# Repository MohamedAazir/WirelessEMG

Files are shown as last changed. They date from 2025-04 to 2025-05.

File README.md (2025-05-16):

# Wireless sEMG Monitoring Device

<div align="center">
  Breadboard Implementation
</div>

This is the repository of a wireless EMG device built for our module **BM2210-Bio Medical Device Design**. The device senses the forearm muscle signals on flexion and extension and then goes through an amplification and filtering part which at last will be transmitted to a laptop where the classification happens. The speciality of the device is that most of the main circuitry of the device was developed using analog electronic components.

## Repository Contents

- 🔌 **Circuit Design**
- 🧪 **Simulation Results**  
- 🔧 **Breadboard Implementation** 
- 🧩 **PCB Design**  
- 🧱 **Enclosure Design**   
- 📡 **Wireless Transmission**  
- 🤖 **ML Model Development**  
- 📄 **Documentation**

## 🔌 Circuit Design

The circuit design consists of four main parts: an **instrumentation amplifier**, a h**igh-pass filter**, a **low-pass filter**, and a **notch filter**. Each part plays a critical role in conditioning the raw bioelectrical signals before further processing or analysis.

### 1. 🎛️ Instrumentation Amplifier

This stage is responsible for amplifying the weak differential signal received from the electrodes while rejecting common-mode noise. It ensures that even very small biopotential signals are amplified to a usable level without being distorted by environmental interference. This is crucial in biomedical applications where the signal strength is often in the microvolt range and needs clean amplification before filtering.
<div align="center">
  Instrumentation Amplifier
</div>

### 2. 🔼 1st Order Active High Pass Filter

We use a **first-order active high-pass filter** with a cut-off frequency of **15.4 Hz**. The main purpose of this filter is to remove low-frequency components from the signal, including **DC offsets and motion artifacts** that can otherwise distort the meaningful parts of the bioelectrical signal. By using an active filter design, we ensure better performance and minimal signal attenuation in the passband.

<div align="center">
  HPF
</div>

### 3. 🔽 5th Order Bessel Low Pass Filter

To preserve the integrity of the signal's shape while eliminating high-frequency noise, we implement a **fifth-order Bessel low-pass filter**. This is achieved using a cascaded system comprising one 1st order active low-pass filter and two 2nd order active low-pass filters. The overall cut-off frequency is around **450 Hz to 460 Hz**. The Bessel filter is chosen for its linear phase response, which helps maintain the waveform fidelity of the signal—an important factor for downstream analysis and visualization.

<div align="center">
  LPF
</div>

### 4. 🚫 Twin-T Notch Filter

To eliminate **powerline interference at 50 Hz**, we use a twin-T notch filter. This type of filter is highly effective at attenuating a narrow frequency band, in this case, the frequency commonly introduced by electrical noise in power systems. Our implementation includes five potentiometers to fine-tune the filter: three are used to precisely set the notch frequency, and two are used to adjust the desired roll-off. This allows for flexibility in tuning and ensures that the filter performs effectively in different environments.

<div align="center">
  Notch Filter
</div>

## Simulation Results

We simulated our designed circuit using LT spice software where we able to visualize the frequency response of each filtering stage.  

<div align="center">
  HP Filter
</div>

The frequency response after the High pass filter

<div align="center">
  HP Filter
</div>

The frequency response after the Low pass filter

<div align="center">
  HP Filter
</div>

The frequency response after the Notch filter

## Breadboard Implementation

The breadboard implementation was used in the early stages for prototyping and testing the EMG signal acquisition, filtering, and wireless transmission before finalizing the PCB. It serves as a reference for understanding the initial circuit layout and testing procedure.

<div align="center">
  breadboard
</div>

## PCB Design

When designing the printed circuit board (PCB) for our wireless sEMG monitoring device, we utilized EasyEDA
software to design a **4-layer PCB**. This tool allowed us to efficiently create and simulate the PCB layout, ensuring optimal design for
signal conditioning, sampling, and wireless transmission. EasyEDA’s user-friendly interface and extensive
library of components made it well-suited for the development of this biomedical application. By leveraging
its advanced features, we were able to streamline the PCB design process and ensure the circuit met the
requirements of the wireless sEMG monitoring system.

<div align="center">
  PCB Layout
</div>

After finalizing the PCB, we choosed JLC PCB which is a professional PCB Manufacturer for the production of our PCBs.

<div align="center">
  PCB 3D Layout
</div>

## Enclosure Design

We used SOLIDWORKS software for the designing of the enclosure. The enclosure consists of a top lid, bottom part, and a battery compartment. The device is designed as a compact wearable design which makes it easy to fetch the EMG signals.
<div align="center">
  Enclosure1
</div>

<div align="center">
  Enclosure2
</div>

<div align="center">
  Enclosure3
</div>

## Coding & Wireless Transmission

The final filtered signal is transmissed using Wifi through an ESP32 micro controller to the host computer. The computer then samples the signal and sends it through a digital filtering process using the **scipy** library. Then the final values are saved as a .csv file to be classified in the ML model.

## ML Model Development

A detailed description of the ML model is shown [here](MLmodel/)

## Our Team 

- Praveen Samuditha
- Hansani Kaumadhi
- Mohamed Aazir

<div align="center">
  Enclosure3
</div>

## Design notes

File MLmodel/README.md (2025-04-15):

# 🤖 Wrist Flexion Detection - ML Model

This is a part of our **Biomedical Device Design** project. It includes a machine learning pipeline to classify wrist flexion based on biosignal input.

---

## 🧩 Overview

This includes:

- Training a **Random Forest Classifier** using handcrafted features
- signal classification display via **Streamlit** app
- A lightweight CLI tool for batch or test use

---

## 📁 Files in This Folder

| File | Description |
|---|---|
| `random_forest_updated.py` | Trains the model and saves it as `.joblib` |
| `app_updated.py` | Streamlit-based app for uploading and classifying signals|
| `real_time_clf.py` | CLI tool for running classification from CSV input |
| `random_forest_updated_model.joblib` | Trained model file (generated after training) |

---

## 📊 Features Used for Classification

From each `Amplitude` signal, we extract **7 statistical features**:

- Mean
- Standard Deviation
- Maximum
- Minimum
- Range
- Median
- Root Mean Square (RMS)

<p align="center">
  
</p>

These features are passed to the Random Forest model for classification.

## 📊 Model Evaluation

<p align="center">
  
</p>

---

## 🖼️ App Preview

<p align="center">
  
  
</p>

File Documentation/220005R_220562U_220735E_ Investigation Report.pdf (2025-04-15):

# Investigation Report

### Team MediCore Innovations


# BM2210 - Bio Medical Device Design

## Group Members

Name | Index Number
Aazir M. A. M. Samuditha H. K. P. Yashodhara M. H. K. | 220005R 220562U 220735E

## Contents

1 Introduction | 3
2 Our Strategic Focus | 3
3 Need 1: Arterial Blood Speed Measuring Device | 4
4 Need 2: Automated Laparoscopic Intracorporeal Knotting Device | 6
5 Need 3: Low-Cost Wireless sEMG Signal Detection System for Wrists | 8
6 Needs Screening | 10
7 Conclusion | 11
8 References | 12

## 1 Introduction

Medicore Innovations is a startup focused on about biomedical product design and development. We’re a bunch of second-year students studying biomedical electronic engineering. Our goal is to shake things up in healthcare and come up with cool, new ways to make medical tech better and easier to get for everyone.

## 2 Our Strategic Focus

### 2.1 Mission

Our mission is to transform healthcare by designing cutting-edge biomedical devices that are not only innovative but also highly affordable, with a strong focus on serving the Sri Lankan market.

### 2.2 Our Focus

Despite our current limits in sophisticated anatomy and complex electronics, Medicore Innovations focuses on creativity and resourcefulness, leveraging the skills of its driven team of undergraduates. Through leveraging a solid basis in fundamental electronics and an unwavering dedication to education, the firm hopes to enhance healthcare accessibility and cost. They focus on developing affordable biomedical devices that satisfy the needs of healthcare providers, NGOs, government agencies, and people looking for affordable medical solutions, while overcoming obstacles like time constraints and a lack of local resources. They primarily target the South Asian market, with Sri Lanka as their primary market.

## 3 Need 1: Arterial Blood Speed Measuring Device

### 3.1 Introduction and Background

Accurately measuring arterial blood flow is super important in healthcare, especially during emergencies like accidents. It helps us figure out if blood vessels are working right or if there’s a blockage that needs quick attention. Right now, we use blood speed measuring tools that rely on Doppler ultrasound tech. This tech sends out an ultrasound wave and checks how it bounces back from moving blood cells to see how fast the blood is flowing. But here’s the catch: in Sri Lanka, these devices can cost around 2 lakhs or even more. That makes it hard for many folks to get their hands on them. We need a more affordable option designed for the local market. Better access means better diagnostics without breaking the bank.

### 3.2 Source in the medical field

Resource Person: A vascular surgeon from Teaching Hospital Peradeniya
We consulted a vascular surgeon from Teaching Hospital Peradeniya regarding the need for an affordable arterial blood speed measuring device. Their expertise highlighted the high cost and limited accessibility of current devices in Sri Lanka, which hampers timely diagnosis and treatment of vascular issues, especially in emergency situations.

### 3.3 Need Statement

Problem: Medical professionals often face challenges in assessing arterial blood flow in emergency situations, such as accidents, due to the high cost and limited accessibility of current Doppler-based blood speed measuring devices. This can delay critical diagnostics and treatment, particularly in resource-limited settings like Sri Lanka.
Population: Doctors and emergency medical professionals, as well as patients requiring immediate evaluation of blood flow, especially in trauma cases.
Outcome: Develop an affordable arterial blood speed measuring device using Doppler ultrasound technology, specifically designed for the Sri Lankan market, to improve accessibility, enhance diagnostic accuracy, and expedite emergency care.

### 3.4 Existing Solutions

Current methods to measure how fast blood moves in arteries use Doppler ultrasound technology. This tech is popular in hospitals for checking health. Companies like D-Brown, Siemens, and GE Healthcare make devices that are super accurate. They give quick info on blood flow speed, which is important for finding blockages or other blood vessel problems. These machines have fancy sensors that can measure without hurting the patient and do it well, but the problem is they can cost a lot, often more than 2 lakhs. That makes it hard to get to places like Sri Lanka. Because of the high price and the need for special training to run these machines, many healthcare providers can’t adopt them easily in areas with limited resources.

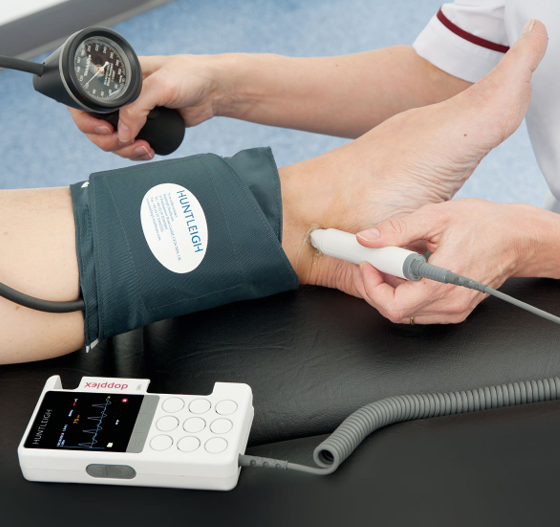
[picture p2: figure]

Figure 1: Existing Device for Arterial Blood Speed Measuring

### 3.5 Stakeholder and Market Analysis

Hospitals and Clinics: Healthcare providers, especially in areas with few resources, can really boost their diagnostic skills with an affordable device that measures arterial blood speed. Faster diagnostics can mean quicker treatments. That’s great for patient outcomes! Plus, hospitals won’t spend as much on importing pricey equipment. They can also offer better services to more people.
Doctors and Emergency Medical Professionals: Doctors will get a handy, budgetfriendly tool for checking blood flow in urgent situations. This helps them spot vascular problems quicker. Emergency professionals can make decisions fast, especially in trauma cases where keeping an eye on blood flow is super important.
Medical Device Manufacturers: Developing a low-cost Doppler-based blood speed measuring device opens a big chance in the market, especially in places like Sri Lanka. As more folks need easy-to-use diagnostic tools, manufacturers can reach out to underserved areas where low prices matter. Sure, the first costs of making them might be tough, but there’s a great chance for lots of use because everyone wants affordable healthcare.

The market for monitoring blood flow devices is growing consistently. There’s more cardiovascular disease and trauma happening around the world. Yet, the big challenge is still how affordable these devices are, particularly in developing countries. If we can provide a cost-effective solution, it might unlock new markets and help fulfill the rising wish for accessible medical diagnostics.

## 4 Need 2: Automated Laparoscopic Intracorporeal Knotting Device

### 4.1 Introduction and Background

Laparoscopic surgery is a common practice in the medical field because of its benefits of reduced recovery time, minimal scarring and lower risk of infection. However, intracorporeal knot tying, a key step in procedures such as suturing during laparoscopy, is one of the most technically challenging tasks for surgeons. The complexity of manually tying knots in a limited space can increase the risk of errors, increase the time of the surgery and lead to complications. The use of an automated device to perform laparoscopic knotting can reduce the technical burden on surgeons and reduce operation time.

### 4.2 Source in the medical field

Resource Person: A vascular surgeon from Teaching Hospital Peradeniya Additionally, the surgeon emphasized the challenges faced during laparoscopic surgeries, specifically with intracorporeal knotting. The complexity of manually tying knots in small spaces increases the risk of surgical errors and extends operation times, highlighting the need for an automated knotting device to improve efficiency and reduce risks.

### 4.3 Need Statement

Problem:Surgeons face difficulties when doing intracorporeal knotting during laparoscopic surgeries due to the complexity of manually tying knots in small spaces which can increase the risk of surgical errors and extend operation times.
Population: Surgeons performing laparoscopic procedures and patients who are going through these surgeries.
Outcome: Create a device that automates intracorporeal knotting to improve surgical efficiency, reduce errors and decrease the time required for laparoscopic operations.

### 4.4 Existing Solutions

Current solutions to intracorporeal knot tying in laparoscopic surgery include manual knot tying techniques and the use of pre-tied knot devices. But these methods come with limitations:
Manual Knot Tying: requires a lot of training and precision. Surgeons must be highly skilled to tie knots in limited spaces, which can lead to fatigue, errors and extended surgery time.
Pre-Tied Knot Devices: Eventhough pre-tied knots reduce the technical challenge, they lack flexibility in terms of custom knot placement and tightness.

Automated devices that perform suturing exist, but they are either too complex or costly, with limited availability in many regions including Sri Lanka. There is still a significant gap in the development of a user-friendly device for automating intracorporeal knotting.

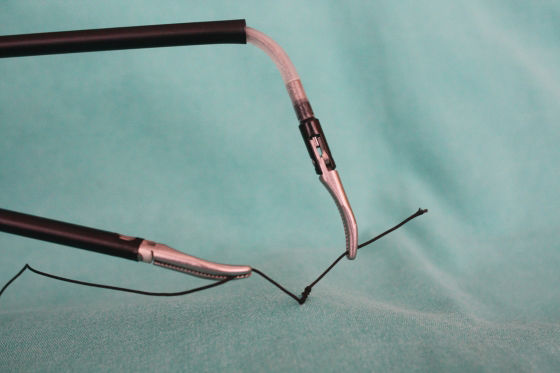
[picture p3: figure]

Figure 2: Existing Surgical Equipments for Intracorporeal Knotting

### 4.5 Stakeholder and Market Analysis

Patients: Patients who are going through laparoscopic surgery can benefit from shorter operation times, fewer complications and faster recovery as automated knotting can reduce surgical errors.
Surgeons:Surgeons will have an easier and more efficient method for knot tying, reducing stress and the probability of errors. Automation can free surgeons from repetitive time-consuming tasks and improve overall precision.
Hospitals and Surgical Centers: Healthcare providers can improve operating room efficiency and reduce costs associated with longer surgical procedures. Shorter surgery times also increase the number of surgeries that can be performed in a day improving income of the hospital.
Medical Device Manufacturers: The development of an automated intracorporeal knotting device presents a significant market opportunity. As laparoscopic surgery continues to expand globally, there is increasing demand for tools that improve surgical efficiency and outcomes.

The global market for laparoscopic devices is drastically increasing with the rising demand for minimally invasive surgeries. As the market expands, there is an increasing need for automation in surgical tasks that are time-consuming or technically challenging. An automated intracorporeal knotting device can meet this demand by improving surgeon performance and patient outcomes. Challenge may be the initial cost of developing and marketing the device, but the potential for widespread usage is high due to the benefits in terms of efficiency and safety. The market for such devices is expected to increase, especially in developed countries where laparoscopic surgeries are widely used.

## 5 Need 3: Low-Cost Wireless sEMG Signal Detection System for Wrists

### 5.1 Introduction and Background

Surface electromyography (sEMG) is a widely used technique to assess muscle activity and performance. Monitoring muscle health and performance is crucial for athletes, especially to track muscle fatigue, recovery, and potential abnormalities. Wrist muscles are particularly prone to fatigue due to repetitive movements in sports such as tennis, golf, and weightlifting. Traditional sEMG systems can be bulky, wired, and impractical for daily use. A wireless sEMG signal detection system for the wrist would provide real-time muscle monitoring in a convenient and wearable format, offering athletes a better idea of their muscle condition and performance while reducing the risk of injury.

### 5.2 Source in the medical field

Resource Person: A 2nd year MBBS undergraduate from University of Colombo
He provided us with the discussed problem and the need for a low cost wireless sEMG system for people specially in the field of sports.

### 5.3 Need Statement

Problem: Athletes often face challenges in monitoring their wrist muscles’ health and performance due to limitations in existing wired sEMG devices, which are bulky and unsuitable for daily, real-time tracking of muscle fatigue and abnormalities.
Population: Athletes and sportspersons who require daily monitoring of their wrist muscles to assess fatigue, prevent injury, and ensure optimal performance at a reasonable cost.
Outcome: Develop a wireless sEMG detection system for wrists that allows real-time monitoring of muscle fatigue and abnormalities. This system should improve athletic performance, prevent injuries, and enable daily, non-invasive monitoring.

### 5.4 Existing Solutions

Current sEMG systems include wired devices and sensors placed on the skin to detect muscle activity. While effective for clinical settings, they pose several limitations in sports and daily use:
Wired sEMG Devices: Though accurate, these systems limit movement, making them unsuitable for dynamic sports. The wires and bulky setup create discomfort, which can distract athletes from their activities.
Wearable Fitness Trackers: Some devices monitor general muscle performance, but they lack the precision of sEMG for detecting muscle fatigue and specific abnormalities. Wireless sEMG Devices: Existing wireless options are often expensive, and their bulkiness reduces comfort, particularly for sportspersons who need lightweight, flexible, and user-friendly designs.

There is a significant opportunity for a lightweight, wireless sEMG system that is cost-effective and designed specifically for daily monitoring of wrist muscles.

### 5.5 Stakeholder and Market Analysis

Athletes and Sportspersons: Athletes can benefit from precise, real-time data on wrist muscle performance, helping prevent overuse injuries, fatigue, and abnormal strain. Daily monitoring ensures better recovery and peak performance during training and competition.
Sports Medicine and Rehabilitation Professionals: A wireless sEMG system enables sports doctors and physiotherapists to monitor and track muscle health remotely, adjusting training or recovery programs based on real-time data.
Fitness Trainers: Coaches and trainers can use this device to improve training schedules by understanding an athlete’s muscle fatigue and recovery needs more accurately. Medical Device Manufacturers: There is a strong market for wearable, non-invasive, real-time monitoring devices in the sports and healthcare industries. The growing interest in personalized health data tracking provides a good opportunity for manufacturers.

The market for wireless sEMG devices is expanding as athletes and healthcare professionals seek more sophisticated tools for performance monitoring and injury prevention. This device can be a cost-effective solution for continuous wrist muscle monitoring, appealing to both professionals and everyday athletes. Though initial development and production costs may pose a challenge, the potential for widespread usage in sports medicine and fitness is significant, particularly in regions where injury prevention and performance tracking are a priority.

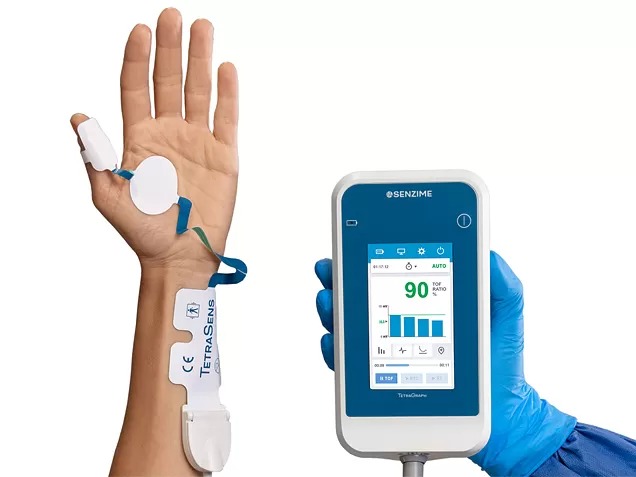
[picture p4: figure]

Figure 3: Wrist Muscle Activity Monitoring - An Improved Method

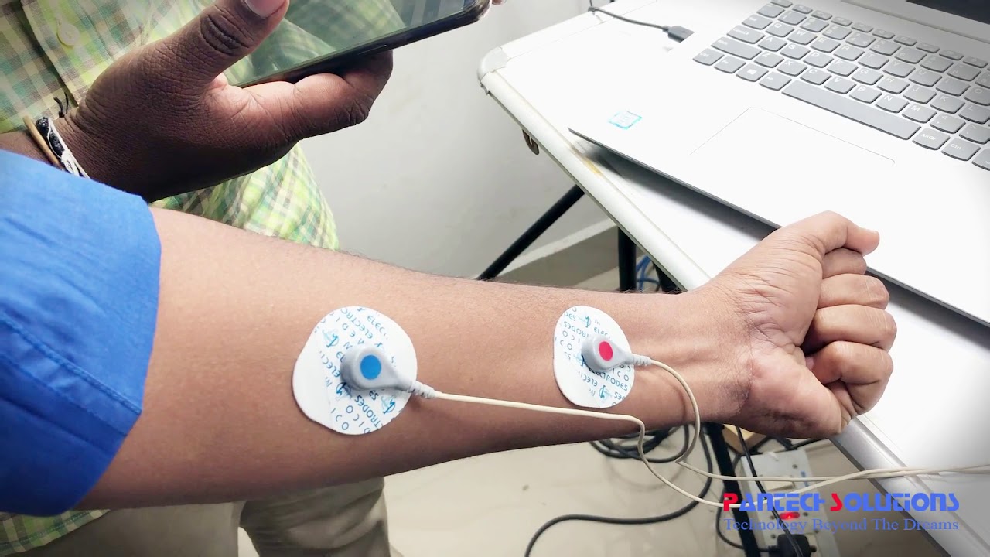
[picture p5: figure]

Figure 4: Wrist Muscle Activity Monitoring - A Conventional Method

## 6 Needs Screening

We considered the above problems and carried out a screening process by allocating marks. Then we selected the most suitable problem by the rankings.

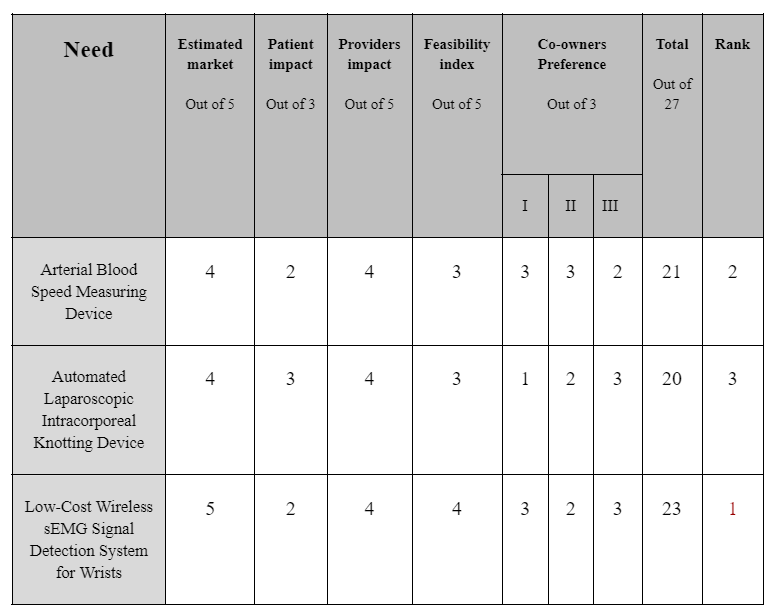
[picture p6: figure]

## 7 Conclusion

In conclusion, we identified ”Need 3: Low-Cost Wireless sEMG Signal Detection System for Wrists” as it meets a vital demand for real-time, non-invasive muscle activity monitoring. This tool can provide insightful information about how muscles work, which is helpful for clinical diagnoses, sports performance, and rehabilitation. In comparison to the other demands, it is a highly influential initiative because of its potential to improve patient care and provide more effective muscle testing in a variety of contexts.

## 8 References

- S. R. Jernigan, G. Chanoit, A. Veeramani, S. B. Owen, M. Hilliard, D. Cormier,
B. Laffitte, G. Buckner, ”A laparoscopic knot-tying device for minimally invasive cardiac surgery,” European Journal of Cardio-Thoracic Surgery, vol. 37, no. 3, pp. 626–630, Mar. 2010, doi: 10.1016/j.ejcts.2009.09.024. (https://doi.org/10.1016/j.ejcts.2009.09.024)
- T. G¨opel, F. H¨artl, A. Schneider, et al., ”Automation of a suturing device for minimally invasive surgery,” Surg Endosc, vol. 25, pp. 2100–2104, 2011, doi: 10.1007/s00464-010-1532-x. (https://doi.org/10.1007/s00464-010-1532-x)
- 18.102MUL, ”Laparoscopic Intracorporeal Suturing: Fundamentals and Tips & Tricks for New Learners,” YouTube, Aug. 7, 2015. [Online]. Available: https: //www.youtube.com/watch?v=U36O18Whc9c. [Accessed: Sep. 16, 2024].
- A. Yousefian, S. Roy, B. Gosselin, ”A Low-power wireless multi-channel surface EMG sensor with simplified ADPCM data compression,” 2013 IEEE International Symposium on Circuits and Systems (ISCAS), Beijing, China, 2013, pp. 2287-2290, doi: 10.1109/ISCAS.2013.6572334. (https://doi.org/10.1109/ISCAS.2013.6572334)
- Z. Liang, X. Wang, J. Guo, et al., ”A Wireless High-Quality Soft and Portable Wrist-Worn System for sEMG Signal Detection,” Micromachines, vol. 14, no. 5, p. 1085, 2023, doi: 10.3390/mi14051085. (https://doi.org/10.3390/mi14051085)
- D. Wu, T. Peng, S. Zhang, et al., ”A Surface Electromyography (sEMG) System Applied for Grip Force Monitoring,” Sensors, vol. 24, no. 12, p. 3818, 2024, doi: 10.3390/s24123818. (https://doi.org/10.3390/s24123818)
- Case, Michelle & Micheli, Matthew & Arroyo, Daniel & Hillard, Jeremy & Kocanda, Martin. (2013). Ultrasonic Blood Flow Sensing using Doppler Velocimetry. International Journal on Smart Sensing and Intelligent Systems. 6. 1298-1316. 10.21307/ijssis-2017-591. https://www.researchgate.net/publication/285948521_Ultrasonic_blood_flow_sensing_using_doppler_velocimetry
- Google Patents, https://patentimages.storage.googleapis.com/2a/fe/b7\protect\penalty\z@/d904046acea2c9/US5409010.pdf. [Accessed: Sep. 16, 2024]. Kirk Beach, John Overbeck. Vector Doppler medical devices for blood velocity studies.[Accessed: Sep. 16, 2024] .Kirk Beach, John Overbeck. Vector doppler medical devices for blood velocity studies.

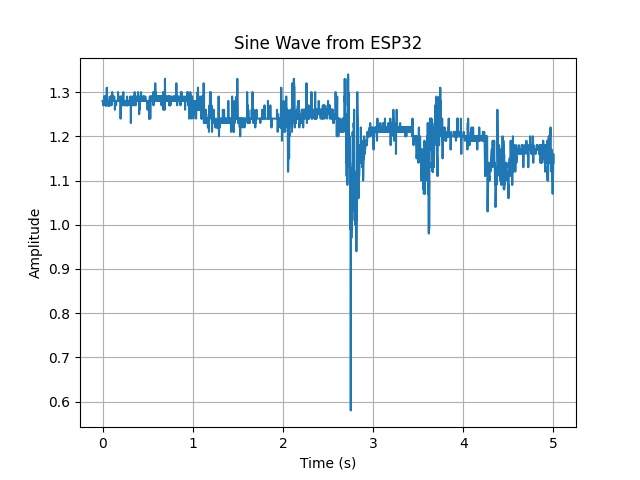
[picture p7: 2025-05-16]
Code/Figure_2.png

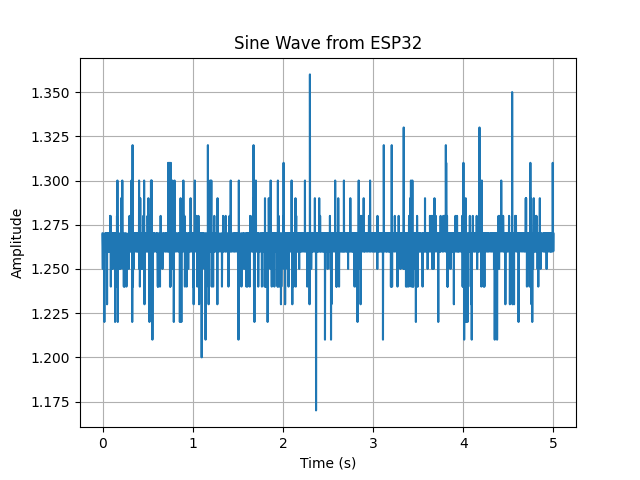
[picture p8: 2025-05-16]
Code/Figure_1.png

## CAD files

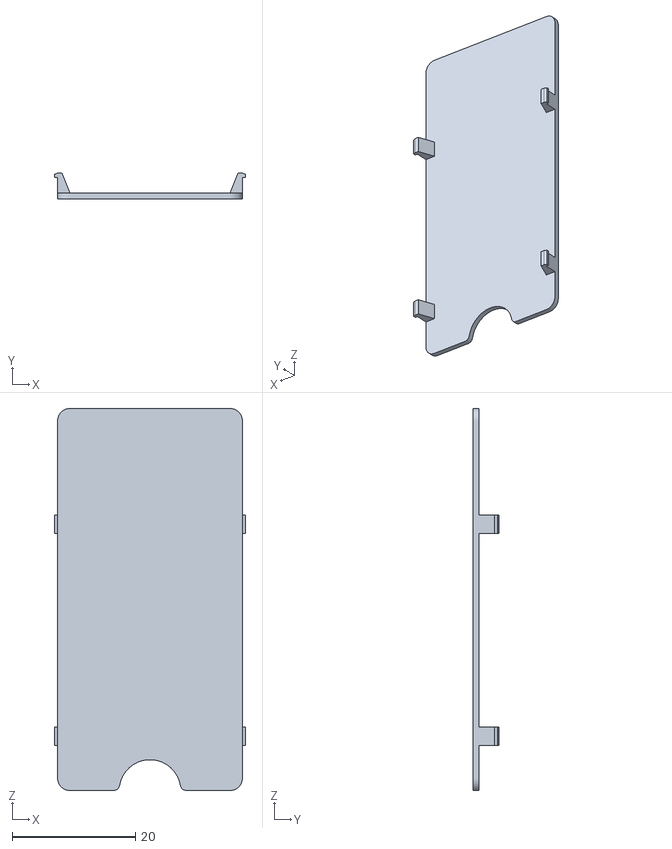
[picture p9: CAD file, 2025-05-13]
Enclosure/3D view/EMG - battery cover emg-2(high quality).STL
31.0 x 4.20 x 62.0

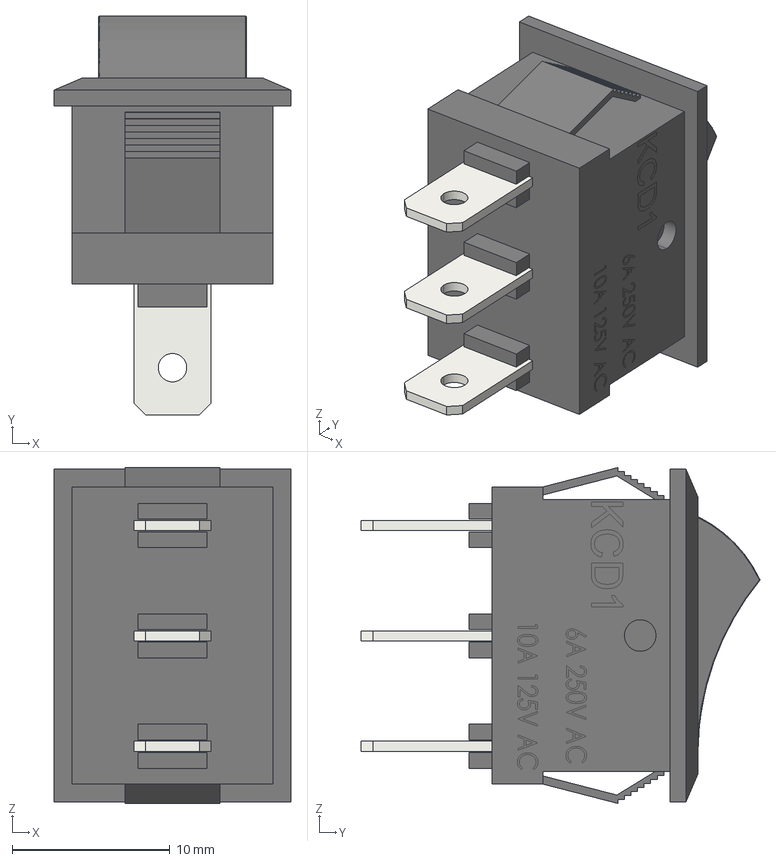
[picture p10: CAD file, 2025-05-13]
Enclosure/interruptor-liga-desliga-6a-250v-spdt-1.snapshot.2/panel_on-off_spdt.step
15.0 x 25.3 x 21.3 mm

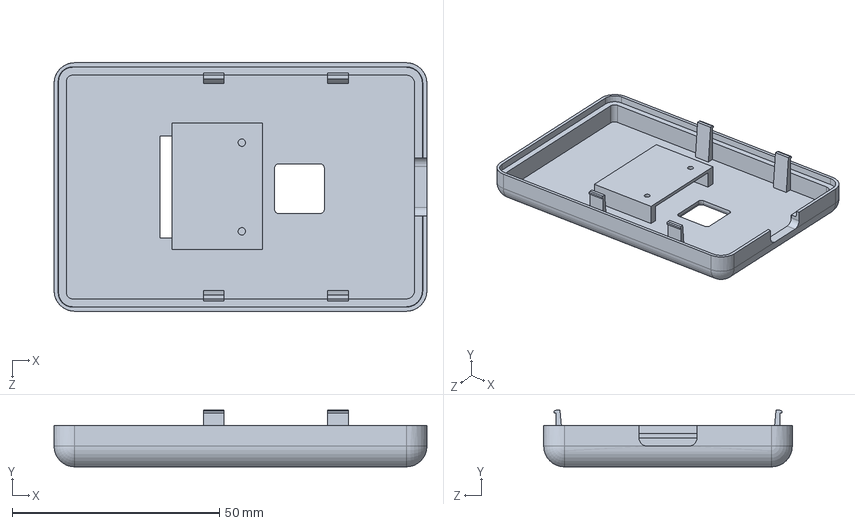
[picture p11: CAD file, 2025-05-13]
Enclosure/lid.SLDPRT
90.0 x 13.7 x 60.0 mm

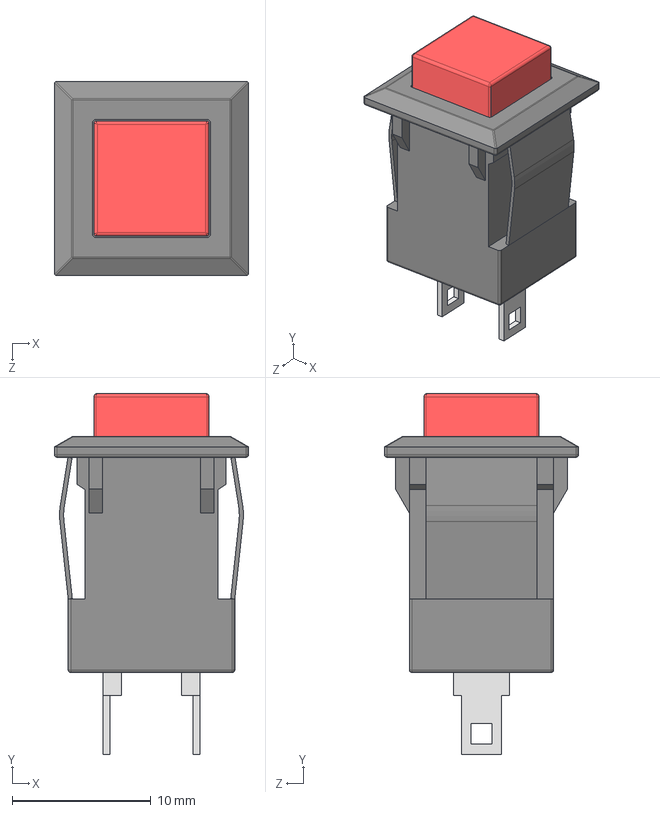
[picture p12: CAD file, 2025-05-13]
Enclosure/PS1057ARED/3D/PS1057ARED.stp
14.0 x 26.0 x 14.0 mm

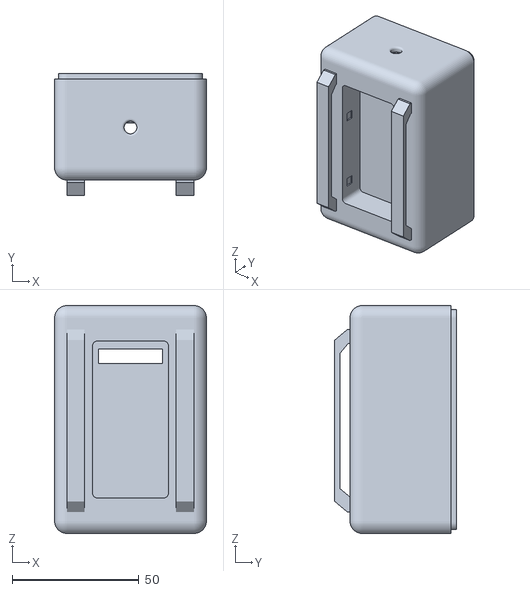
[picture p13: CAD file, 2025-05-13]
Enclosure/3D view/EMG - Base-1.STL
60.0 x 48.0 x 90.0

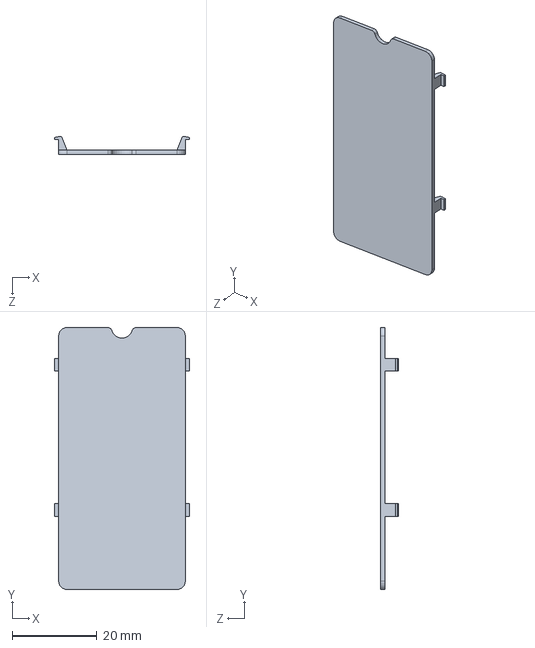
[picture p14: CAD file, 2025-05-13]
Enclosure/battery cover emg.SLDPRT
32.0 x 62.0 x 4.20 mm

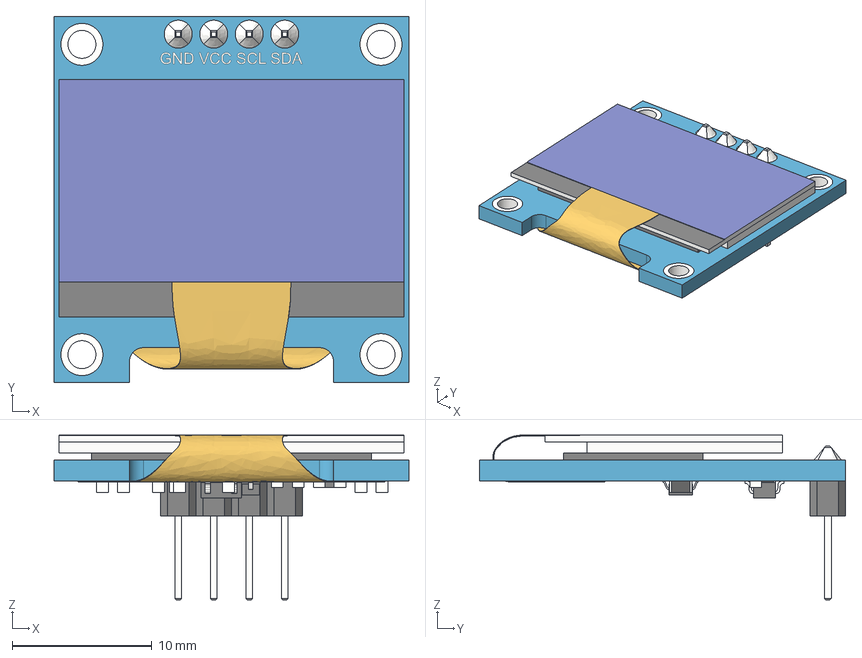
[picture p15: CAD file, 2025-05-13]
Enclosure/SSD1306_OLED_Display(128x64).step
25.4 x 26.2 x 11.8 mm
board
screen
pin_header
soldering
smd_capacitor
smd_capacitor (1)
914_smd_resistor
472_smd_resistor x 3
t4_smd_diode
smd_capacitor (2)
smd_capacitor (3)
smd_capacitor (4)
smd_capacitor (5)
smd_capacitor (6)
472_smd_resistor (1)
SOT-23_XC6206 v3
smd_capacitor (7)
flat_cable

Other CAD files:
Enclosure/3D view/EMG - lid-2(high quality).STL
Enclosure/Base.SLDPRT
Enclosure/SSD1306_OLED_Display(128x64).SLDPRT

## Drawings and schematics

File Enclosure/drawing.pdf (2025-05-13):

E E

F F

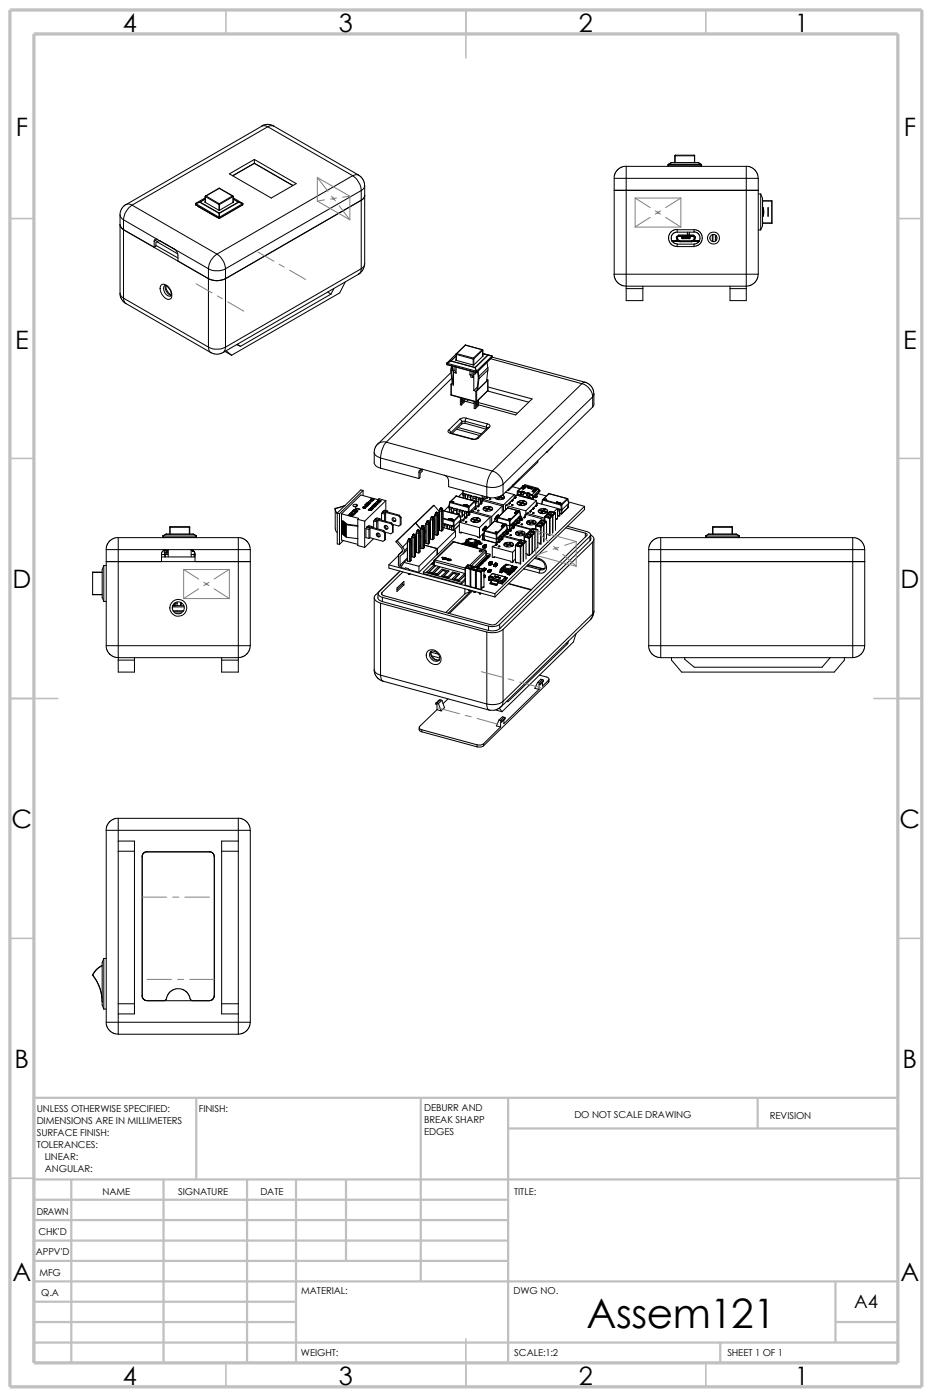
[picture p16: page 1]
TITLE:; DWG NO.; SCALE:1:2; SHEET 1 OF 1; WEIGHT:; MATERIAL:; REVISION; DATE; SIGNATURE DRAWN; MFG; FINISH:; EDGES; NAME; DEBURR AND BREAK SHARP; Assem121

UNLESS OTHERWISE SPECIFIED:
DIMENSIONS ARE IN MILLIMETERS
SURFACE FINISH:
TOLERANCES:
LINEAR:
ANGULAR:

DO NOT SCALE DRAWING

CHK'D
APPV'D

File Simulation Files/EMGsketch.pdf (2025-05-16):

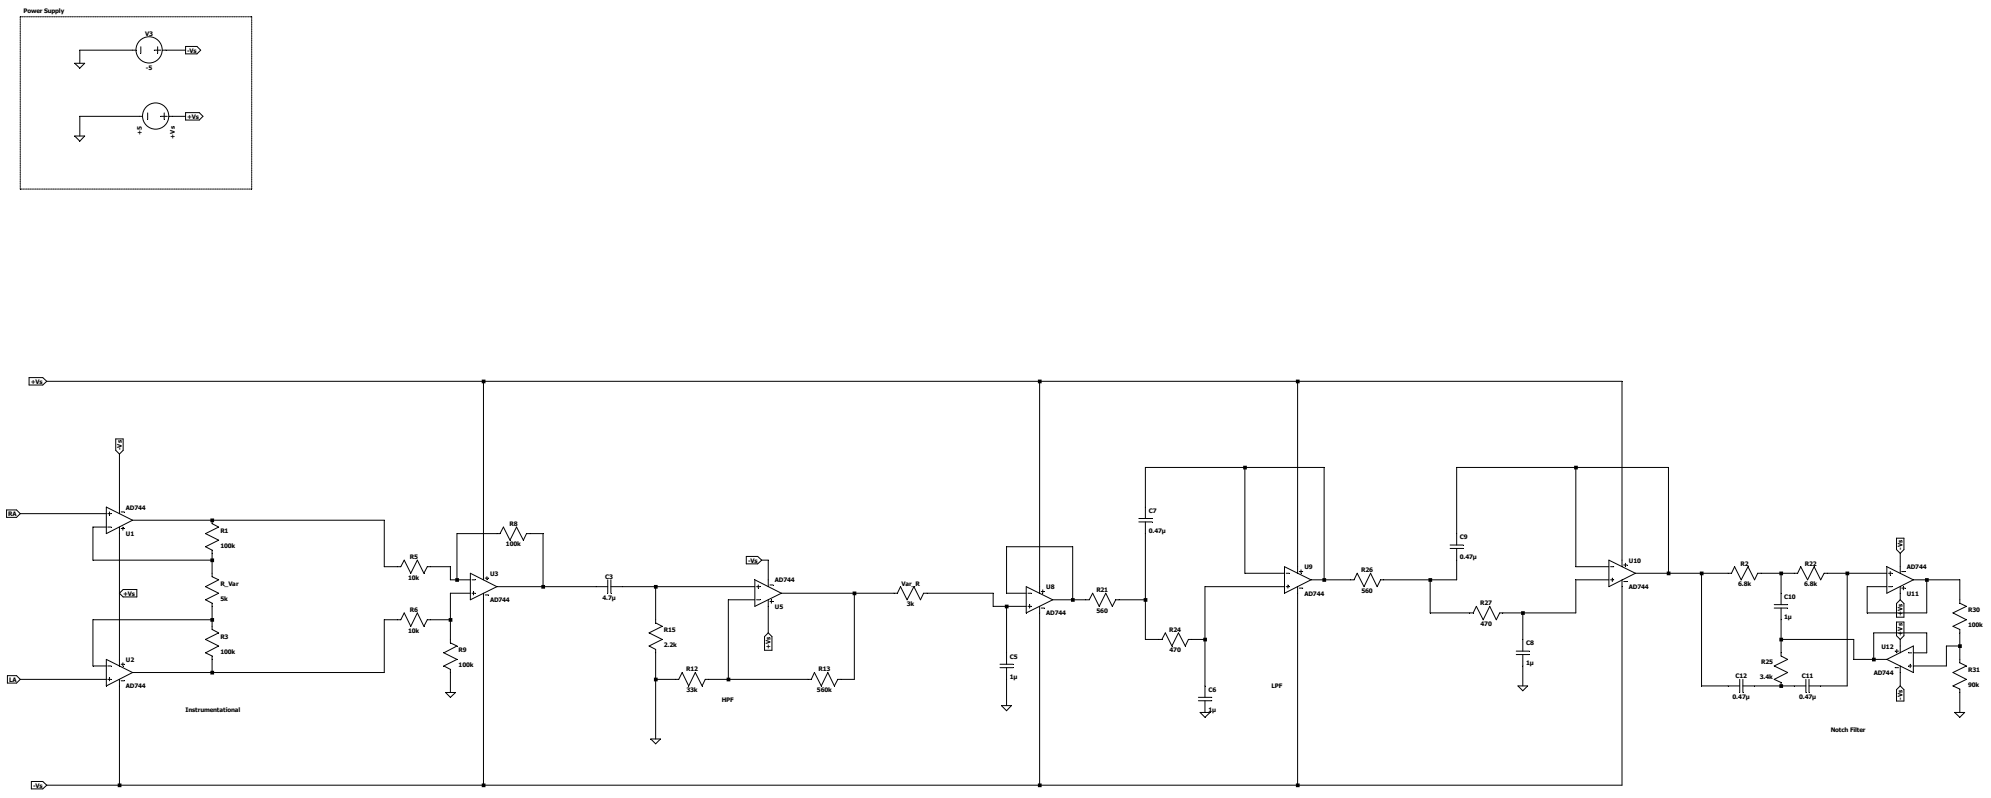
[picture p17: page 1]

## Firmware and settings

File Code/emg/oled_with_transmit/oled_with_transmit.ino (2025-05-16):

#include <Adafruit_GFX.h>
#include <Adafruit_SSD1306.h>
#include <WiFi.h>
#include <WebServer.h>
#include <math.h>

// Define OLED display dimensions
#define SCREEN_WIDTH 128
#define SCREEN_HEIGHT 64
#define SSD1306_I2C_ADDRESS 0x3C // in Adafruit_SSD1306.h
// Define OLED reset pin (set to -1 if not used)
#define OLED_RESET    -1
Adafruit_SSD1306 display(SCREEN_WIDTH, SCREEN_HEIGHT, &Wire, OLED_RESET);

// Battery level pin and variables
#define BATTERY_PIN 35
#define BUTTON_PIN 15
int batteryLevel = 0;
bool isRecording = false;

// Wi-Fi Access Point credentials
const char* ssid = "Medicore";
const char* password = "12345678";

// Create an HTTP server instance
WebServer server(80);

// EMG signal sampling parameters
const int sampleCount = 10000;  // Number of samples to transmit (time duration)
const int analogPin = 34;     // Analog input pin
const int offset = 2;
float analogValues[sampleCount];  // Array to hold sampled analog values

// Function to collect analog readings
void collectAnalogReadings() {
  for (int i = 0; i < sampleCount; i++) {
    analogValues[i] = (analogRead(analogPin) * 3.3) / 4095.0 - offset; // Convert ADC value to voltage
    delayMicroseconds(500); // 100 kHz sampling rate
  }
}

// Function to handle root page requests
void handleRoot() {
  collectAnalogReadings(); // Collect EMG signal samples from analog pin

  String jsonResponse = "[";

  // Convert sampled analog data to JSON format
  for (int i = 0; i < sampleCount; i++) {
    jsonResponse += String(analogValues[i]);
    if (i < sampleCount - 1) {
      jsonResponse += ",";
    }
  }
  jsonResponse += "]";

  // Send JSON response
  server.send(200, "application/json", jsonResponse);
}

void setup() {
  // Initialize serial communication
  Serial.begin(115200);

  // Start Wi-Fi as Access Point
  WiFi.softAP(ssid, password);
  Serial.println("Wi-Fi Access Point started");
  Serial.print("IP Address: ");
  Serial.println(WiFi.softAPIP());

  // Configure HTTP server routes
  server.on("/", handleRoot);

  // Start the HTTP server
  server.begin();
  Serial.println("HTTP server started");

  // Initialize OLED display
  if (!display.begin(SSD1306_SWITCHCAPVCC, 0x3C)) {
    Serial.println(F("SSD1306 allocation failed"));
    for (;;);
  }

  // Set up button pin
  pinMode(BUTTON_PIN, INPUT_PULLUP);

  // Clear the display buffer
  display.clearDisplay();

  // Display the welcome screen
  //displayWelcomeScreen();
  delay(3000); // Wait for 3 seconds

  // Clear the screen for the next message
  display.clearDisplay();
  display.display();
}

void loop() {
  // // Read battery level
  // batteryLevel = analogRead(BATTERY_PIN);

  // // Check if the button is pressed
  // if (digitalRead(BUTTON_PIN) == LOW && !isRecording) {
  //   isRecording = true;

  //   server.handleClient();
    
  //   displayRecordingScreen();
  //   delay(3000); // Simulate recording time
  //   displayDoneScreen();
  //   delay(2000); // Wait before turning off the display
  //   display.clearDisplay();
  //   display.display();
  //   isRecording = false;
  // } else if (!isRecording) {
  //   // Display the message and battery indicator
  //   displayMessageWithBattery("Click the button to start recording");
  displayWelcomeScreen();
  delay(1000);
  }



void displayWelcomeScreen() {
  // Display welcome message
  display.setTextSize(1);
  display.setTextColor(SSD1306_WHITE);
  display.setCursor(10, 20);
  display.setTextSize(2);
  display.println("WiEMG");
  display.setTextSize(1);
  display.setCursor(50, 45);
  display.println("by Medicore ");

  // Update the display with the buffer
  display.display();
}

void displayMessageWithBattery(const char* message) {
  // Clear the display buffer
  display.clearDisplay();

  // Display battery level indicator
  displayBatteryIndicator();

  // Display the main message
  display.setTextSize(1);
  display.setTextColor(SSD1306_WHITE);
  display.setCursor(0, 30);
  display.println(message);

  // Update the display with the buffer
  display.display();
}

void displayRecordingScreen() {
  // Clear the display buffer
  display.clearDisplay();

  // Display "Recording..." message
  display.setTextSize(1);
  display.setTextColor(SSD1306_WHITE);
  display.setCursor(0, 30);
  display.println("Recording......");

  // Update the display with the buffer
  display.display();
}

void displayDoneScreen() {
  // Clear the display buffer
  display.clearDisplay();

  // Display "Done" message
  display.setTextSize(1);
  display.setTextColor(SSD1306_WHITE);
  display.setCursor(0, 30);
  display.println("Done");

  // Update the display with the buffer
  display.display();
}

void displayBatteryIndicator() {
  // Map battery level to a percentage
  int batteryPercent = map(batteryLevel, 0, 4095, 0, 100);

  // Draw the battery outline
  display.drawRect(110, 5, 16, 8, SSD1306_WHITE);
  display.drawRect(126, 7, 2, 4, SSD1306_WHITE); // Battery positive terminal

  // Fill the battery level
  int fillWidth = map(batteryPercent, 0, 100, 0, 14);
  display.fillRect(112, 7, fillWidth, 4, SSD1306_WHITE);

  // Display the percentage value (optional)
  display.setCursor(90, 5);
  display.setTextSize(1);
  display.setTextColor(SSD1306_WHITE);
  display.print(batteryPercent);
  display.print("%");
}

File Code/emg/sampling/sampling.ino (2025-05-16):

// Arduino Code
const int analogPin = 34; // Analog input pin
const int sampleCount = 15000; // Collect samples for 15 seconds at 1 kHz
float analogValues[sampleCount]; // Array to hold analog readings

// Function to collect analog readings
void collectAnalogReadings() {
  for (int i = 0; i < sampleCount; i++) {
    float rawValue = analogRead(analogPin); // Read raw ADC value
    analogValues[i] = (rawValue / 4095.0) * 3.3; // Scale to 0-3.3V (ESP32 ADC range)
    delayMicroseconds(1000); // 1 kHz sampling rate
  }
}

void setup() {
  Serial.begin(115200);
  Serial.println("Sine Wave Data Plotting Started");
}

void loop() {
  collectAnalogReadings();

  // Send analog readings to Serial for plotting
  for (int i = 0; i < sampleCount; i++) {
    Serial.println(analogValues[i]);
  }
}
